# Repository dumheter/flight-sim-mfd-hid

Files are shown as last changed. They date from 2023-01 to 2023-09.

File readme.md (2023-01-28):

# Flight Simulation MFD HID.
Physical representation of the buttons around the multi-function display device, to be used in flight simulation games. Note that most airplanes around that time use a similar MFD unit. F-16, F-15, the US version of the Harrier, etc.  
  
The project invoves a custom made PCB, made in Ki-Cad. It's powered by an Arduino pro micro, which uses an Atmel Atmega32u4. It's main strength it the usb controller inside the chip. It will act as a windows joystick device, with 20 buttons that can be mappend in the game to the DDI/MFD.

## How it works
Gif of first test, irl.  
gif of it in action  
Ki-cad pcb drawing.  
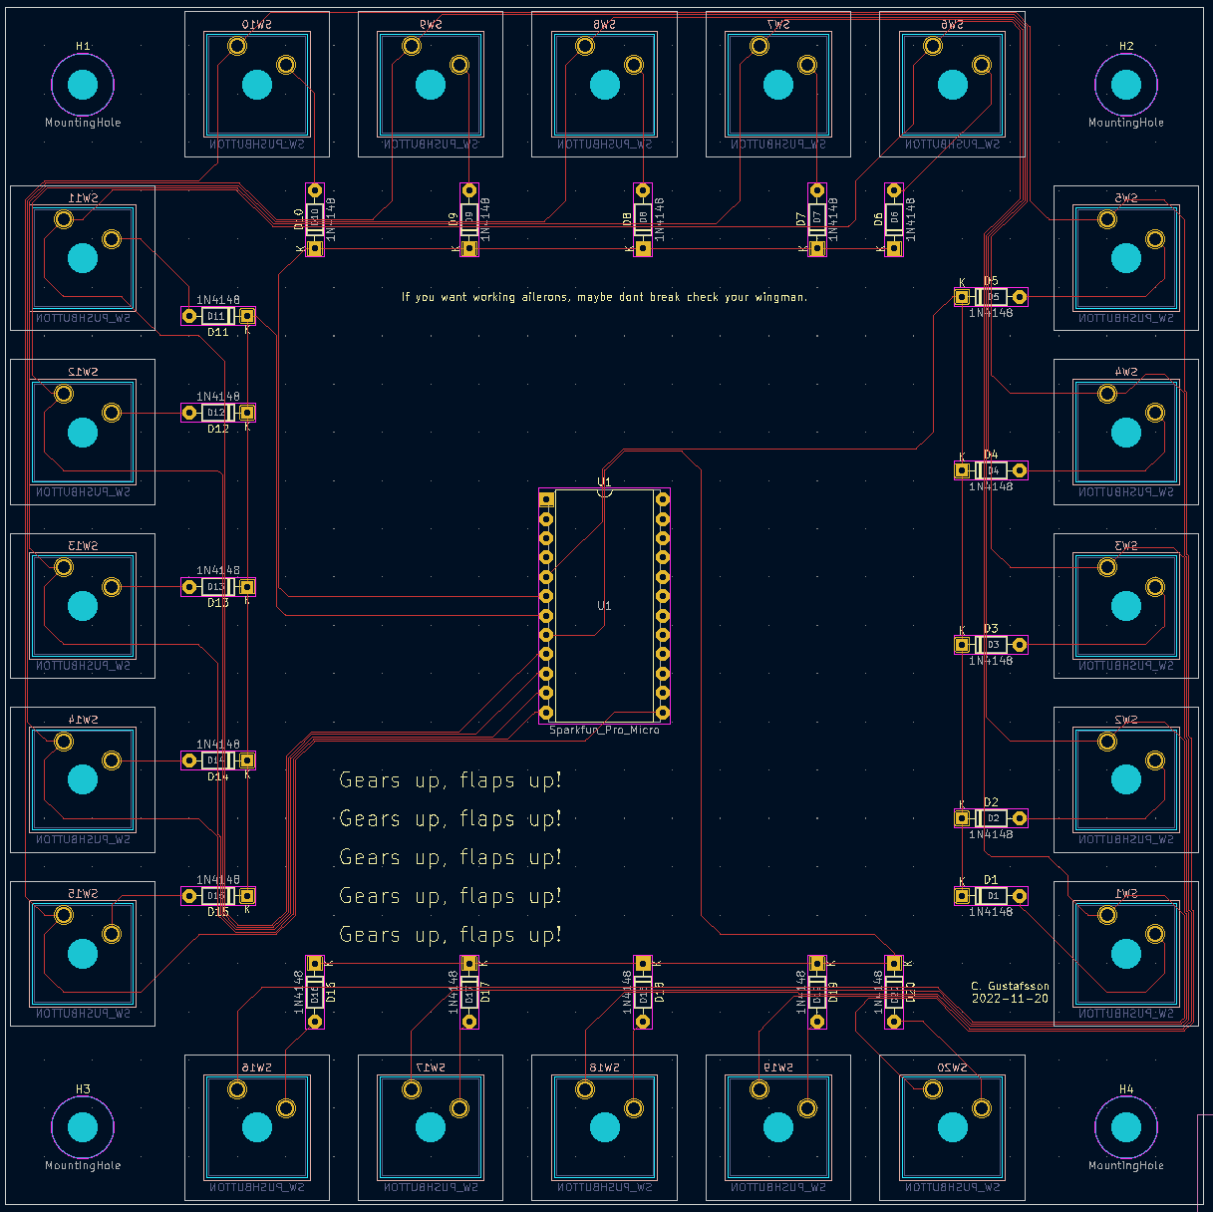
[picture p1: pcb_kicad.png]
pcd kicad drawing
  
Finished pcb, next to my flight stick.  
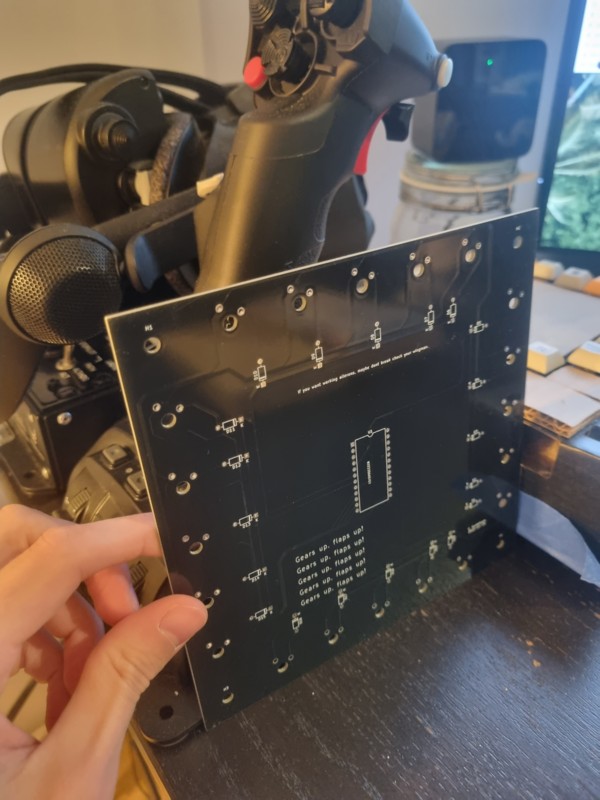
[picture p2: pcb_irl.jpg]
finished pcb
  
How the cockpit look in (dcs) game.  
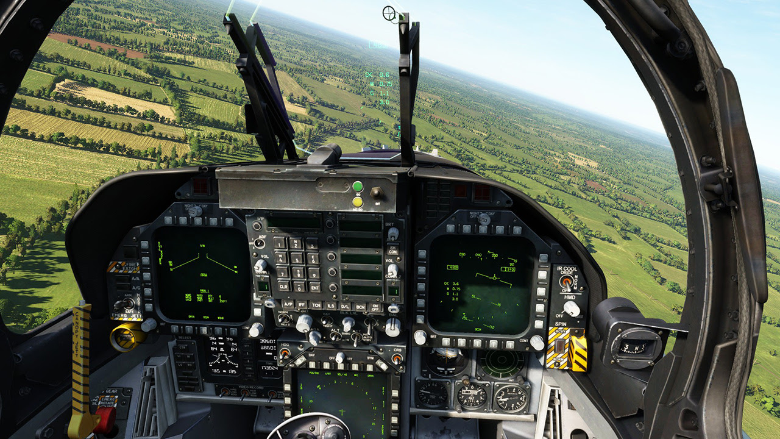
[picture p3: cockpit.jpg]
cockpit


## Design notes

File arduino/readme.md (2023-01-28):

# Firmware for Arduino Pro Micro
Compiled 2023-01-28 on Arduino IDE 2.0.3
## Sparkfun
Find the board on sparkfun  
https://www.sparkfun.com/products/12640  
  
Instruction for how to install the board to Arduino IDE on [Sparkfun's github page](https://github.com/sparkfun/Arduino_Boards)  
  
Also read this guide, is a great resource for this board: https://learn.sparkfun.com/tutorials/pro-micro--fio-v3-hookup-guide  

## ArduinoJoystickLibrary
To utilize the Atmega32u4, I use the [ArduinoJoystickLibrary](https://github.com/MHeironimus/ArduinoJoystickLibrary). The zip can also be found in this folder.

## FlightSimMfd
This is a modified version of spark fun's hardware package. I've changed the usb package name from "SparkFun Pro Micro" to "MFD". Quoting from [source](https://github.com/MHeironimus/ArduinoJoystickLibrary/issues/14): "If your device, is the first device connected to this computer with that vid / pid combination, it will be displayed with your usb_product name.".  
  
Install in "C:\Users\<COMPUTERNAME>\AppData\Local\Arduino15\packages".

## Tips
You can use `joy.cpl` to get the pre-installed windows joystick tester program, to see your code in action.  
  
Do not chose the board variant 8MHz 3.3V if you have a 5V board, it will soft brick it, and you have to burn the bootloader again using an external device.

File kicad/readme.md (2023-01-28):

I used kicad 6.0, and the pcbway plugin for kicad to automatically export the files to pcbway.

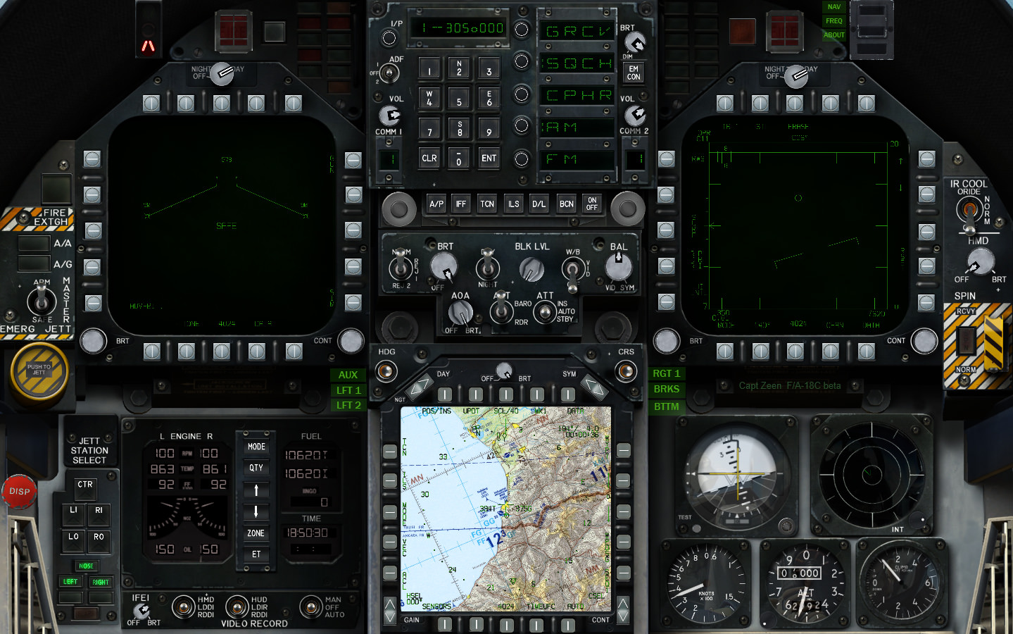
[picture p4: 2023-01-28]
reference HID.jpeg

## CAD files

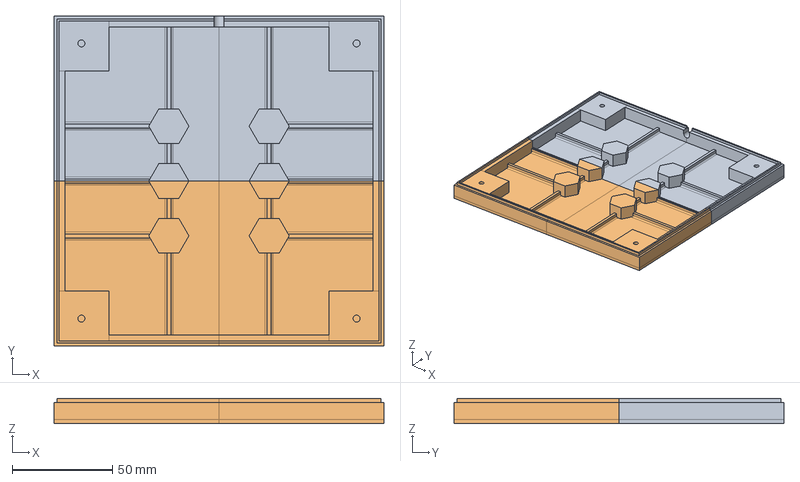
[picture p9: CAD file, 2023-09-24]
case/case_bottom.FCStd
164.5 x 164.5 x 12.7 mm
MultiTransform (Mirror #1)

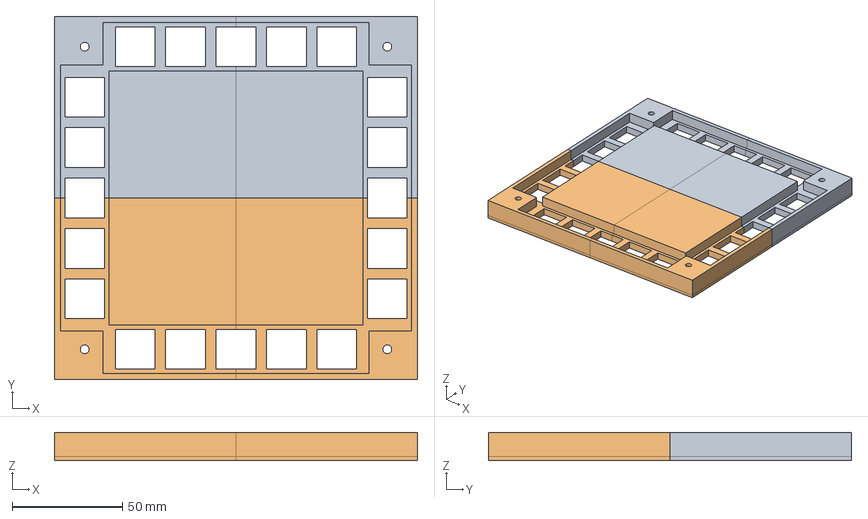
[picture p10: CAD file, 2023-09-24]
case/case_top.FCStd
164.5 x 164.5 x 12.8 mm
Body (Mirror #1)

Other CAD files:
case/case_bottom.stl
case/case_top.stl

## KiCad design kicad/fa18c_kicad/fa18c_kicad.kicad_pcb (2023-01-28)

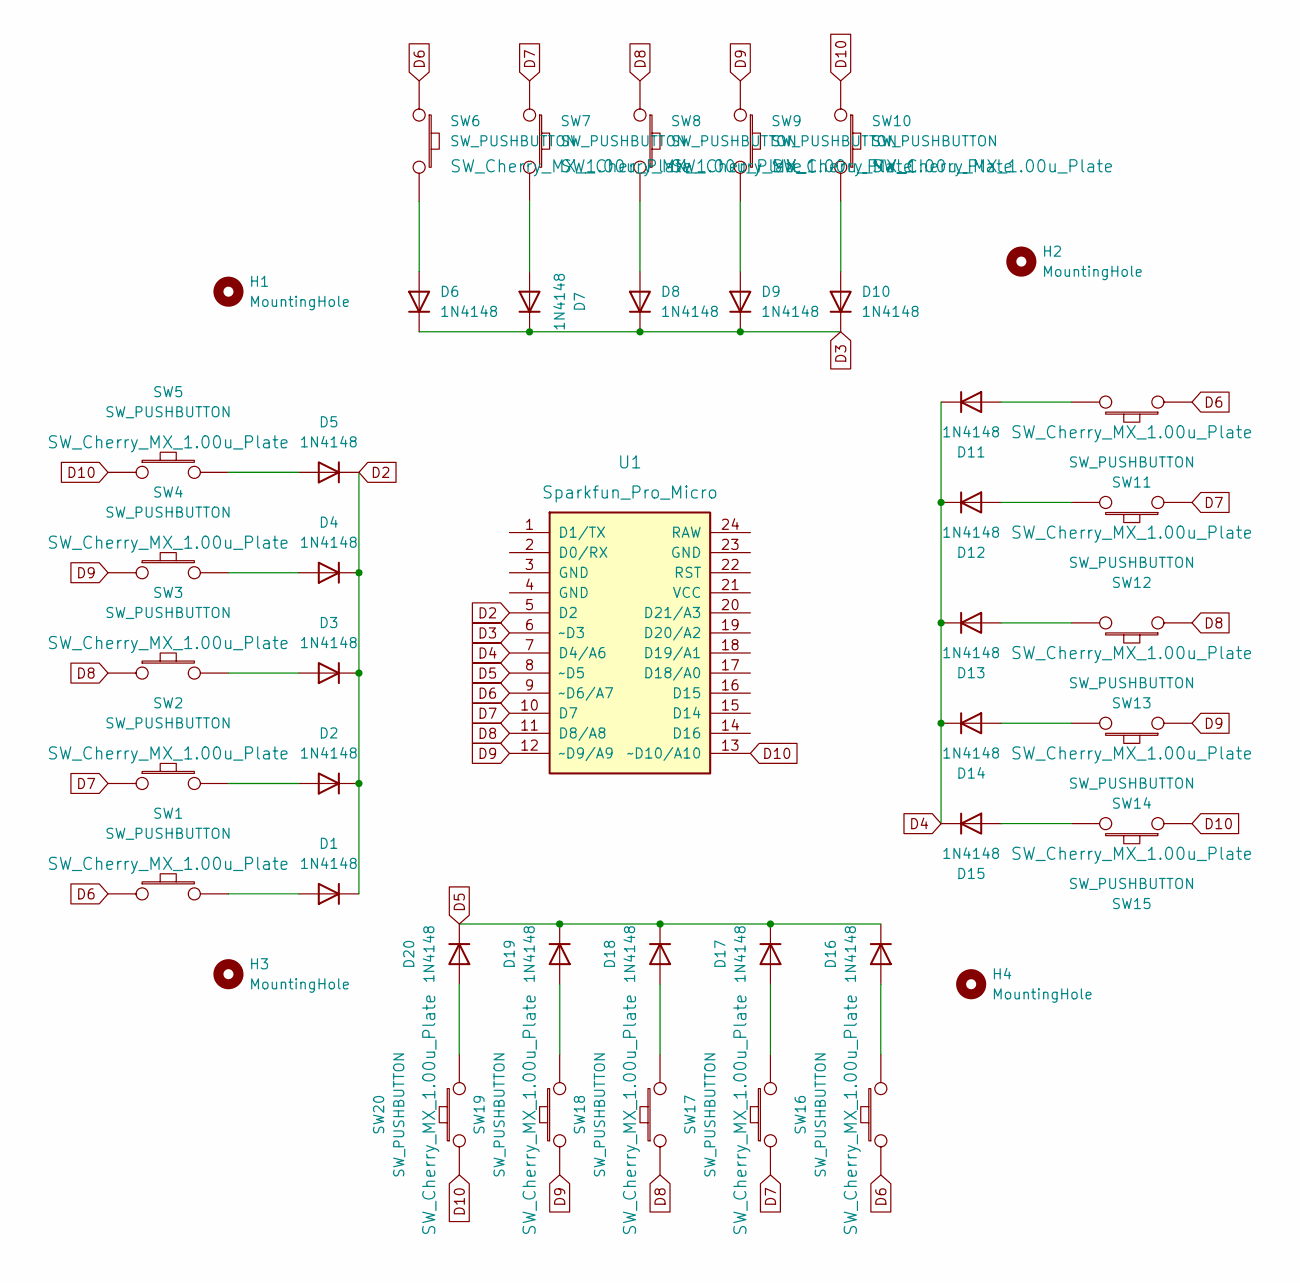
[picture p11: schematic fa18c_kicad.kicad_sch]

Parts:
D1, D2, D3, D4, D5, D6, D7, D8, D9, D10, D11, D12, D13, D14, D15, D16, D17, D18, D19, D20: 1N4148; D_DO-35_SOD27_P7.62mm_Horizontal
H1, H2, H3, H4: MountingHole; MountingHole_4mm
SW1, SW2, SW3, SW4, SW5, SW6, SW7, SW8, SW9, SW10, SW11, SW12, SW13, SW14, SW15, SW16, SW17, SW18, SW19, SW20: SW_PUSHBUTTON; SW_Cherry_MX_1.00u_Plate
U1: Sparkfun_Pro_Micro; DIP-24_W15.24mm

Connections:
D2: D1.1 (K), D2.1 (K), D3.1 (K), D4.1 (K), D5.1 (K), U1.5 (D2)
D3: D6.1 (K), D7.1 (K), D8.1 (K), D9.1 (K), D10.1 (K), U1.6 (~D3)
D4: D11.1 (K), D12.1 (K), D13.1 (K), D14.1 (K), D15.1 (K), U1.7 (D4/A6)
D5: D16.1 (K), D17.1 (K), D18.1 (K), D19.1 (K), D20.1 (K), U1.8 (~D5)
D6: SW1.1, SW6.1, SW11.1, SW16.1, U1.9 (~D6/A7)
D7: SW2.1, SW7.1, SW12.1, SW17.1, U1.10 (D7)
D8: SW3.1, SW8.1, SW13.1, SW18.1, U1.11 (D8/A8)
D9: SW4.1, SW9.1, SW14.1, SW19.1, U1.12 (~D9/A9)
D10: SW5.1, SW10.1, SW15.1, SW20.1, U1.13 (~D10/A10)
unnamed: D1.2 (A), SW1.2
unnamed: D2.2 (A), SW2.2
unnamed: D3.2 (A), SW3.2
unnamed: D4.2 (A), SW4.2
unnamed: D5.2 (A), SW5.2
unnamed: D6.2 (A), SW6.2
unnamed: D7.2 (A), SW7.2
unnamed: D8.2 (A), SW8.2
unnamed: D9.2 (A), SW9.2
unnamed: D10.2 (A), SW10.2
unnamed: D11.2 (A), SW11.2
unnamed: D12.2 (A), SW12.2
unnamed: D13.2 (A), SW13.2
unnamed: D14.2 (A), SW14.2
unnamed: D15.2 (A), SW15.2
unnamed: D16.2 (A), SW16.2
unnamed: D17.2 (A), SW17.2
unnamed: D18.2 (A), SW18.2
unnamed: D19.2 (A), SW19.2
unnamed: D20.2 (A), SW20.2

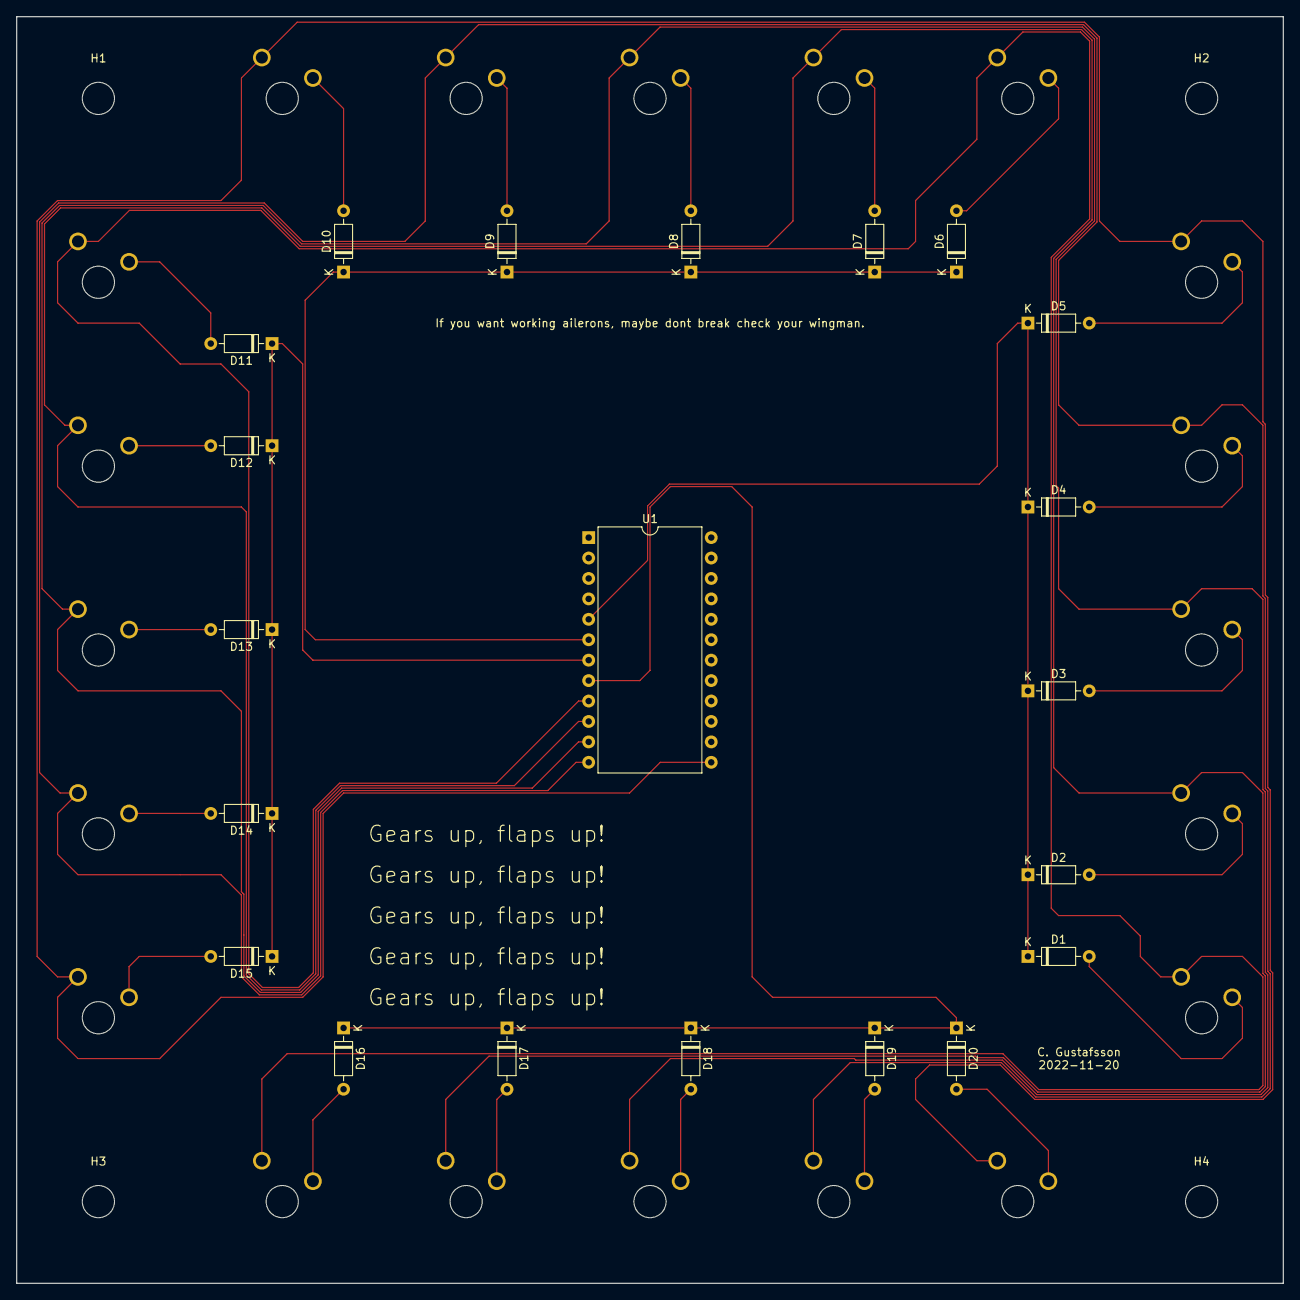
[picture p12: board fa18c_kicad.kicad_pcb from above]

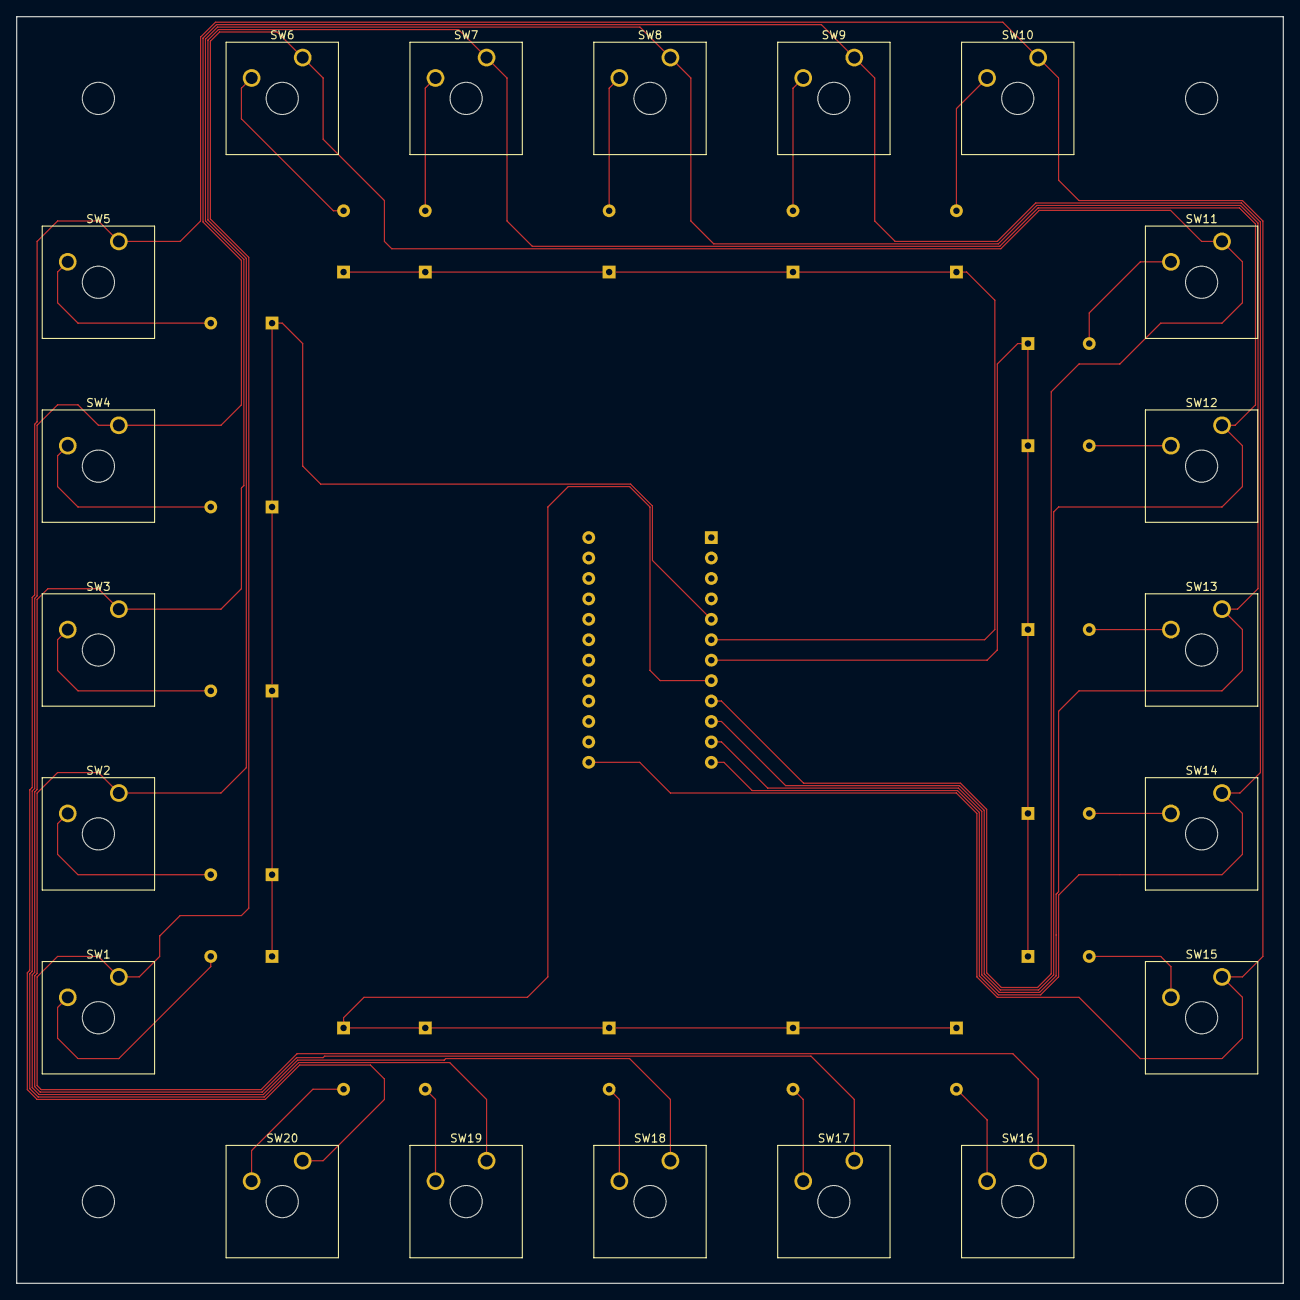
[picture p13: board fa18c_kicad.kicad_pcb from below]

Board: 2 copper layers, 157.5 x 157.5 mm, 45 parts (20 on the bottom side), 29 nets.

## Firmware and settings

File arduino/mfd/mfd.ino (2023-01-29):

#include <Joystick.h>

using Pin = unsigned int;

/// Sink pins will do the digitalRead.
constexpr Pin sink_size = 4;
constexpr Pin sink_pins[sink_size] = {2, 3, 4, 5};

/// Source pins will do the digitalWrite.
constexpr Pin source_size = 5;
constexpr Pin source_pins[source_size] = {6, 7, 8, 9, 10};

Joystick_ joystick;

void setup() {
  for (Pin i = 0; i < sink_size; ++i) {
    pinMode(sink_pins[i], INPUT_PULLUP);
  }

  for (Pin i = 0; i < source_size; ++i) {
    pinMode(source_pins[i], OUTPUT);
  }

  joystick.begin(false /*autosend*/);
}

void loop() {
  for (Pin i = 0; i < source_size; ++i) {
    digitalWrite(source_pins[i], LOW);

    // Debounce the input by reading once, then a bit later, read again.
    // Only if the result is LOW both times should we turn on the button.
    bool states[sink_size];
    for (Pin j = 0; j < sink_size; ++j) {
      states[j] = digitalRead(sink_pins[j]);
    }

    delayMicroseconds(200);

    for (Pin j = 0; j < sink_size; ++j) {
      const auto state = states[j] || digitalRead(sink_pins[j]);

      // We invert the state since we use a pullup, which natrual state is TRUE.
      joystick.setButton((i) + (j) * source_size, !state);
    }

    digitalWrite(source_pins[i], HIGH);
  }

  joystick.sendState();
  delay(4); // 0,2*5 + 4 -> 200/s
}

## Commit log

2023-01-29 Re-write the code to fit a pullup resistor instead of pulldown.
2023-09-24 Designed a case to be 3d printed.
    [case_bottom.FCStd, case_bottom.stl, case_top.FCStd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]
2023-09-24 Fixed mounting hole misaligned.
    [case_bottom.FCStd, case_bottom.stl, case_top.FCStd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]
